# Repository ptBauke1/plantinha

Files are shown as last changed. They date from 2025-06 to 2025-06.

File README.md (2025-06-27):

# Monitor e Irrigador Automático de Vaso de Planta 🌱💧

## Descrição

Este projeto utiliza um sensor de umidade do solo resistivo para monitorar a umidade em um vaso de planta. Com base nas leituras do sensor, um sistema de controle aciona uma pequena bomba d'água para irrigar a planta automaticamente, garantindo que ela receba a quantidade ideal de água.

---

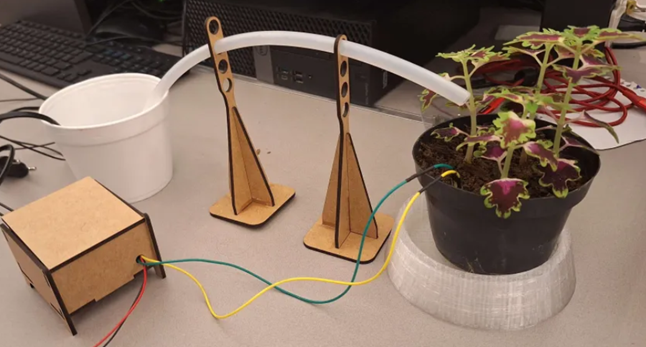
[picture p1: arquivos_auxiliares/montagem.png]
Texto Alternativo Montagem do projeto


## Estrutura do repositorio 📂
```
├─── main.cpp
├─── CmakeLists.txt
├─── pico_sdk_import.cmkae
├─── README.md
├─── Relatorio.pdf
├─── Apresentacao.pdf
├─── calibracao_sensor.xlsx
├───arquivos_auxiliares
├───include
│   └───ssd1306
├───projeto mecanico
│   ├───caixa
│   └───suporte
└───src
    └───ssd1306
```

## Funcionalidades ✨

* **Monitoramento em tempo real:** Acompanha a umidade do solo continuamente.
* **Irrigação automática:** Aciona a bomba d'água quando a umidade cai abaixo de um nível pré-definido.
---

## Hardware Necessário 🔩

* Raspberry Pi Pico
* Sensor de Umidade do Solo Resistivo
* Relé para controle da bomba d'Água
* Bomba d'Água Submersível AC
* Mangueira para a bomba
* Vaso de planta com terra e planta!

---

## Software e Bibliotecas 💻

* O software foi desenvolvido atraves do Visual Studio Code utilizando a SDK disponibilizada pela Raspberry Pi Foundation para o desenvolvimento de seus microcontroladores em C.
* Para o controle do display OLED, utilizou-se a biblioteca SSD1306_OLED, que pode ser conferida no link: https://github.com/gavinlyonsrepo/SSD1306_OLED_PICO
---

## Montagem e Conexões 🔌

Descreva aqui as conexões entre os componentes. Por exemplo:

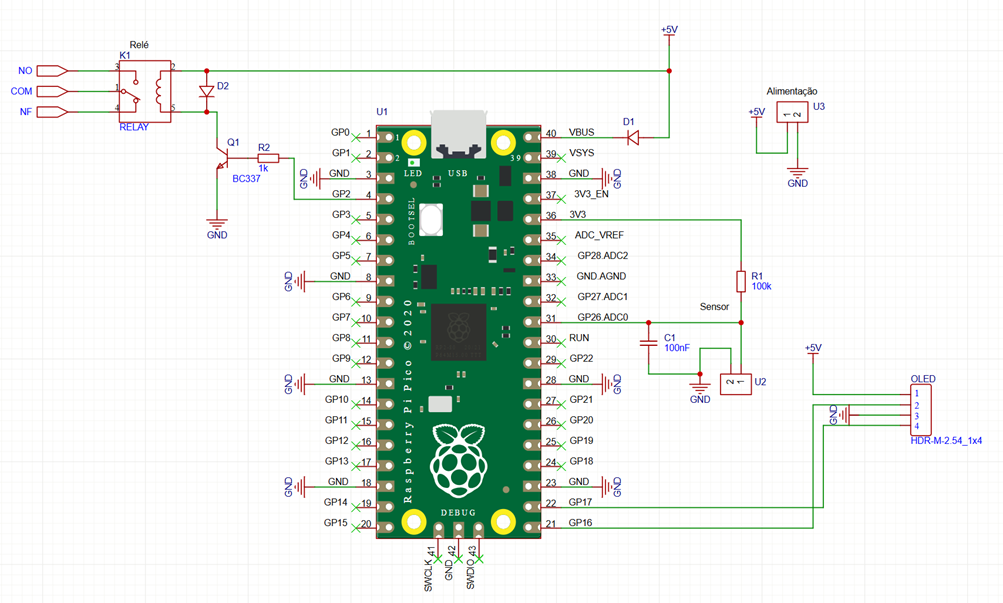
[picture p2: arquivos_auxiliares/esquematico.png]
Esquema eletrico

1.  **Sensor de Umidade:**
    * A variação da corrente do sensor é transformada em variação de tensão pelo divisor resistivo exitente entre o R1 e o proprio sensor 
    * A leitura do sensor é realizada pelo pino 31 da Raspberry Pi Pico, pino no qual o ADC0 do microcontrolador está conectado.
2.  **Módulo Relé e Bomba:**
    * **Módulo Relé:**
        * Base do transistor NPN conectado ao pino GPIO2 do microcontrolador
        * Coletor conectado a bobina do relé
        * Emissor conectado ao GND
        * Outra extremidade da bobina do relé conectada ao +5V.
    * **Bomba:**
        * Fase da bomba conectada ao NF do relé.
3.  **Display OLED**
    * Display conectado nos pinos GPIO16 e GPIO17, utilizando a comunição I2C.
4.  **Alimentação:**
    * Alimentação é fornecida por uma fonte de bancada configurada para +5V.

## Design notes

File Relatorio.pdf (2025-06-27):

Sistema Automatizado para Irrigação de Plantas

Eliana So 1

; Pedro Bauke 1

; Andressa Martins 2

; Rodrigo França 2

1 Aluno do Instituto Mauá de Tecnologia (IMT); 2 Professor do Instituto Mauá de Tecnologia (IMT).

Resumo. Este relatório técnico descreve o desenvolvimento de um sistema automatizado para irrigação de plantas, com foco em otimizar o manejo da umidade do solo em ambientes domésticos. O sistema emprega um sensor de umidade do solo resistivo, escolhido por sua simplicidade e baixo custo , que opera pela variação da resistência conforme a concentração de água e íons no solo. A estrutura mecânica foi construída com MDF e materiais reciclados, utilizando uma bomba d'água para o transporte do líquido. A eletrônica é controlada por um microcontrolador RP2040, que gerencia a leitura do sensor, o acionamento de um relé para a bomba e a exibição de dados em um display OLED. Para realizar a quantificação de umidade foi realizado uma calibração do sensor coletando-se dados do pino de ADC a partir de determinadas concentrações de água. O sistema funcionou devidamente, porém foram identificados problemas de alta sensibilidade do sensor e a necessidade de calibração para diferentes tipos de solo devido à variação na concentração de íons, o que exige ajustes para garantir medições precisas.

Introdução

A umidade é uma grandeza física fundamental em várias aplicações e a sua quantificação é essencial para otimizar desempenhos de sistemas, evitar perdas e gastos e garantir conforto à saúde humana. Para a sua medição são utilizados sensores de umidade que são amplamente utilizados em diversas áreas.
Em indústrias, por exemplo, monitora-se a umidade do ar para evitar problemas de ferrugem e danos às máquinas, além em indústrias alimentícias, controlam a qualidade do produto. No ambiente doméstico, os sensores são integrados em sistemas de aquecimento/refrigeração para otimizar a sua eficiência energética e melhorar a qualidade do ar reduzindo infecções respiratórias e alergias. Uso em agricultura, onde a concentração de água no solo é essencial para o rendimento das culturas, além disso, são ideais para prevenir o crescimento de mofo em plantas e solo.
É perceptível sua alta gama de aplicações em diversos setores, os quais alguns dos seus principais foram citados brevemente. Essa diversificação também se aplica à tecnologia empregada nos sensores, os principais e os mais populares tipos de sensores são os resistivos, capacitivos e de condutividade térmica.
Visando em uma aplicação para automação residencial e agricultura, optou-se a criação de um sistema de irrigação inteligente para vasos de planta domiciliar, visto que, de acordo com o Censo QuintoAndar de Moradia de 2021, 37% dos entrevistados relataram um aumento no hábito de cuidar de plantas ou de jardins durante a pandemia de COVID-19, além de 69% dos entrevistados gostam de cultivar plantas em seus lares.
Para a realização do sistema de irrigação para agradar os amantes de plantas, optou-se na confecção de um sensor de umidade resistivo pela sua simplicidade de design, baixo custo e capacidade de medir grandes variações de umidade.

Material e Métodos

Com o foco na automação residencial, optou-se por utilizar materiais de fácil acesso, como MDF e materiais reciclados, pois dessa forma se torna possível a reprodução do sistema em ambientes residenciais. Na Figura 1 está a montagem final do projeto.

Figura 1 – Montagem final

Mecânica

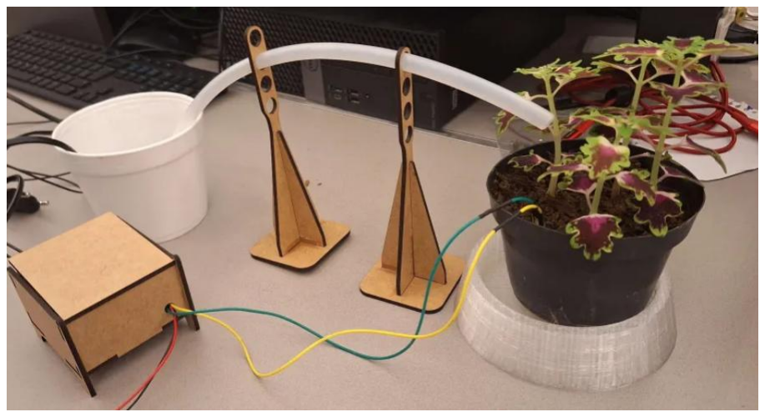
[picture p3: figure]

Para regar a planta é importante qualquer recipiente para armazenar água e um método de transportar o líquido para a planta. Optou-se no uso de um recipiente reciclável (vasilha de isopor) do tamanho ideal para caber uma bomba d’água, que no caso, utilizou-se de uma bomba para fonte de bebedouro para animais de estimação e um tubo de plástico de 10mm de diâmetro para o transportar a água para a planta.
O restante da parte estrutural, utilizou-se de chapas de MDF de 3mm, devido à versatilidade e rápida prototipação. A montagem é formada por um “corpo central”, definida por uma caixa com tampa basculante para comportar toda a eletrônica e um rasgo na parte frontal para o display, além disso, foram feitos “postes” reguláveis para arquear e suportar o tubo de plástico da bomba d’água, pois a fluidez da água depende da sua angulação.
Todos os componentes, para que sejam cortados no corte a laser, foram feitas no Solidworks como demonstra na Figura 2.

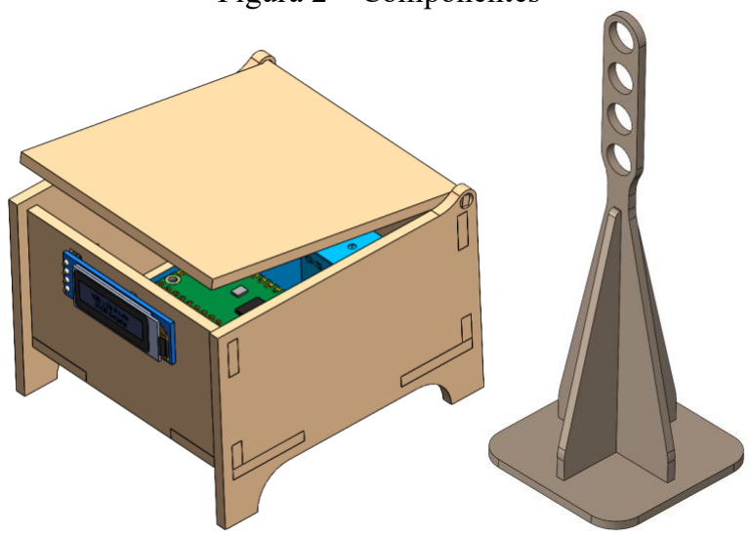
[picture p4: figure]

Figura 2 – Componentes

Sensor

O sensor desenvolvido é um sensor de umidade do solo resistivo, esse tipo de sensor consiste em basicamente dois eletrodos metálicos, ou seja, pode-se utilizar pregos, fios de cobre. A Figura 3 mostra a placa de circuito impresso com duas trilhas paralelas que servem como os eletrodos do sensor.

Figura 3 – Sensor de umidade do solo

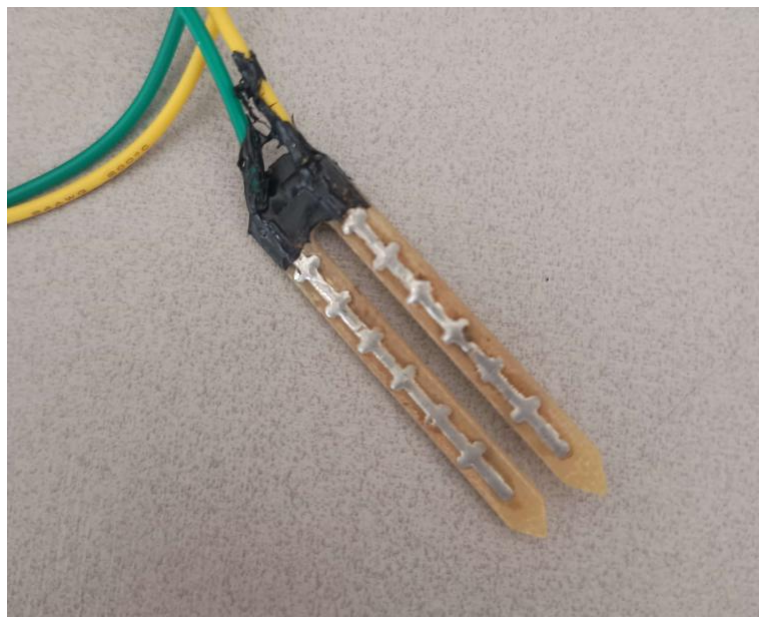
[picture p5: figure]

O sensor é composto por dois eletrodos que são inseridos no solo, e estabelecem uma conexão elétrica através dele. Por estar em constante contato com a umidade, o sensor é suscetível à oxidação e corrosão, um problema comum de se acontecer com eletrônicos, portanto, para aumentar a sua vida útil, as trilhas de cobres da placa foram estanhadas.
Seu funcionamento se dá pela variação da resistência do solo, ou seja, a capacidade do solo de resistir a passagem de corrente elétrica. Isso acontece devido a presença de íons dispersos no solo, e como a água também apresenta íons, quanto maior a concentração de água no solo, mais íons estarão presentes, dessa forma a resistividade diminui e mais elétrons conseguem atravessar entre os eletrodos do sensor.

Eletrônica

Para a criação e fabricação da placa de controle, foi montado o diagrama de blocos ilustrado pela Figura 4, que representa de maneira simples e clara como cada elemento do circuito se comunica, explicitando como os componentes trocam informações entre si.

Figura 4 – Diagrama de blocos do sistema

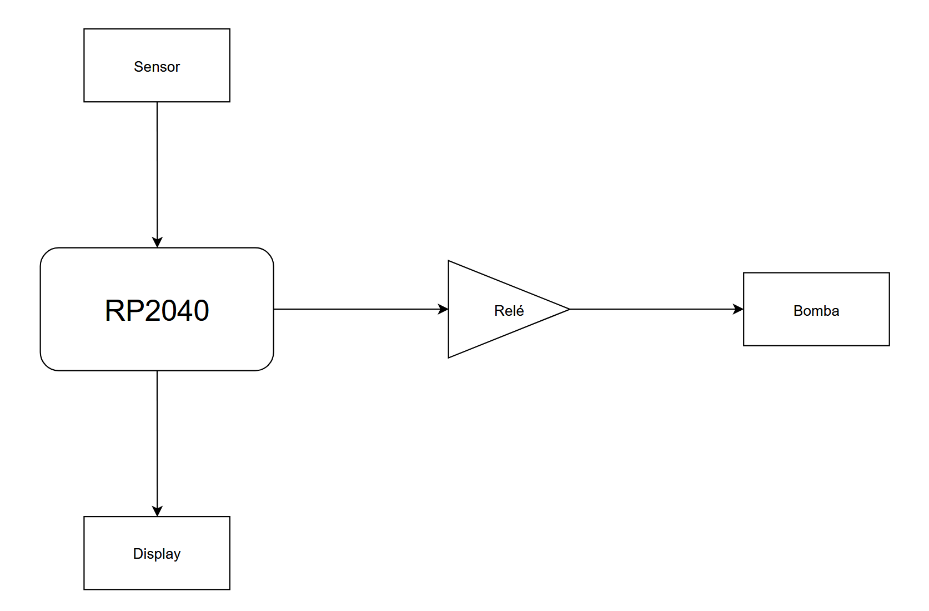
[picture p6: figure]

Com o diagrama de blocos montado, utilizou-se do software EasyEDA para a criação do esquema elétrico e da placa de circuito impresso. As Figura 5 e 6 apresentam o diagrame elétrico e a PCB, respectivamente.

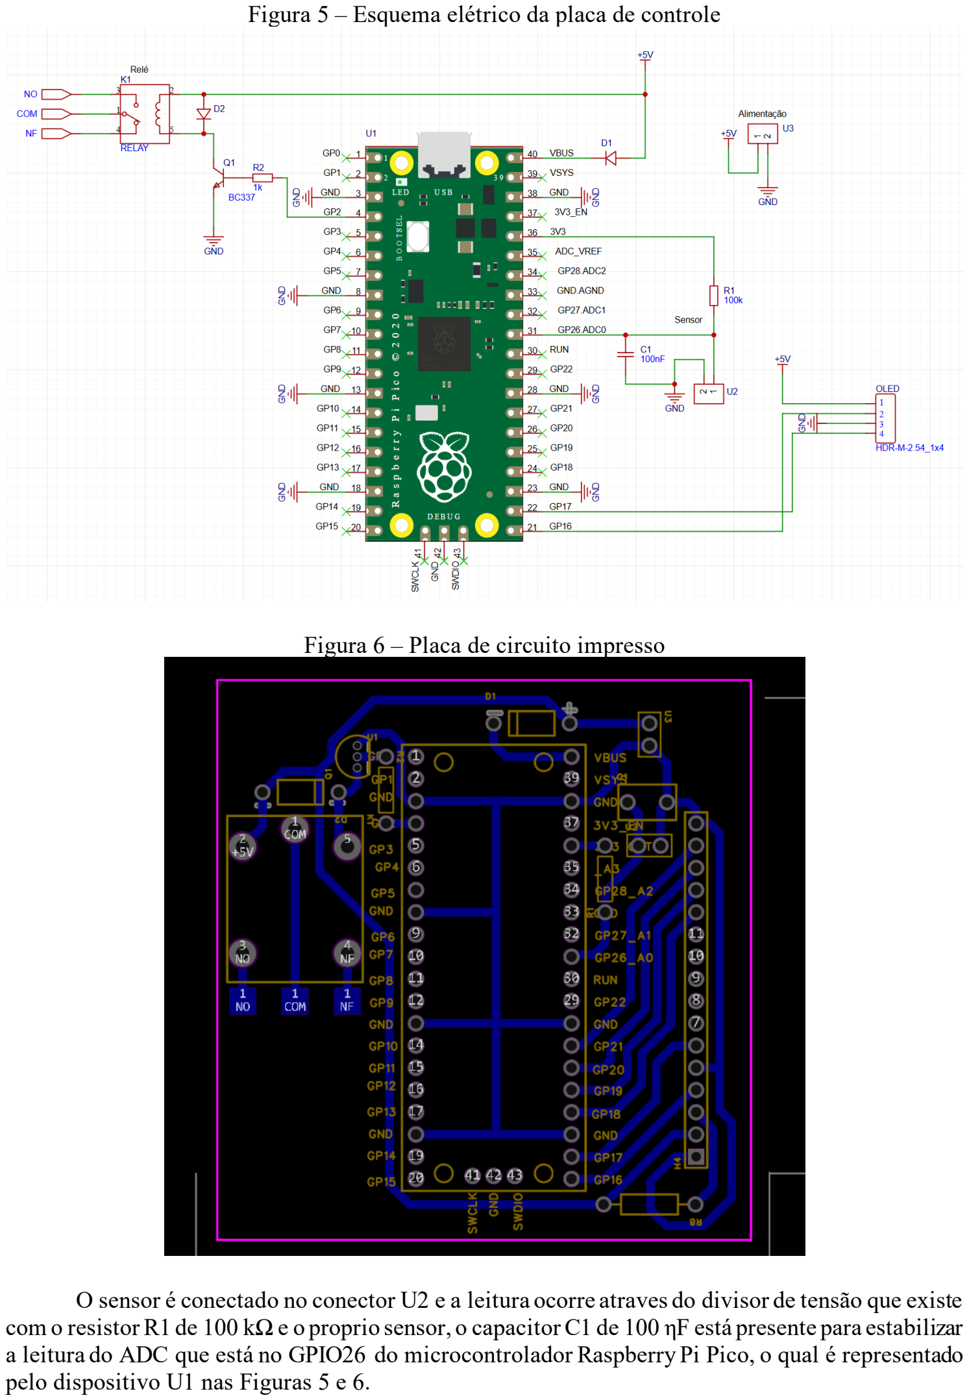
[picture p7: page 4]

Figura 5 – Esquema elétrico da placa de controle

Figura 6 – Placa de circuito impresso

O sensor é conectado no conector U2 e a leitura ocorre atraves do divisor de tensão que existe com o resistor R1 de 100 kΩ e o proprio sensor, o capacitor C1 de 100 ηF está presente para estabilizar a leitura do ADC que está no GPIO26 do microcontrolador Raspberry Pi Pico, o qual é representado pelo dispositivo U1 nas Figuras 5 e 6.

Para o acionamento da bomba, utiliza-se o relé 875B-1CC-F-S, uma vez que a bomba utilizada funciona em corrente alternada e o sistema de controle, em corrente continua. Como o relé necessita de um sinal de +5V para ser acionado e o microcontrolador tem como nível lógico alto +3,3V, um transistor foi adicionado no circuito, agindo como elemento que chaveia a parte que conecta a bobina do relé ao GND.
Além disso, o circuito apresenta um display OLED 128x32, que se comunica com o microcontrolador através do protocolo I2C, para exibir informações como a umidade relativa do solo e o valor lido pelo conversor analógico-digital do RP2040, ilustrado na Figura 7. A PCB apresenta uma barra de 16 vias pois em seua versão inicial, um display LCD era considerado como forma de apresentar as informações.

Figura 7 – Visor OLED para apresentação dos dados

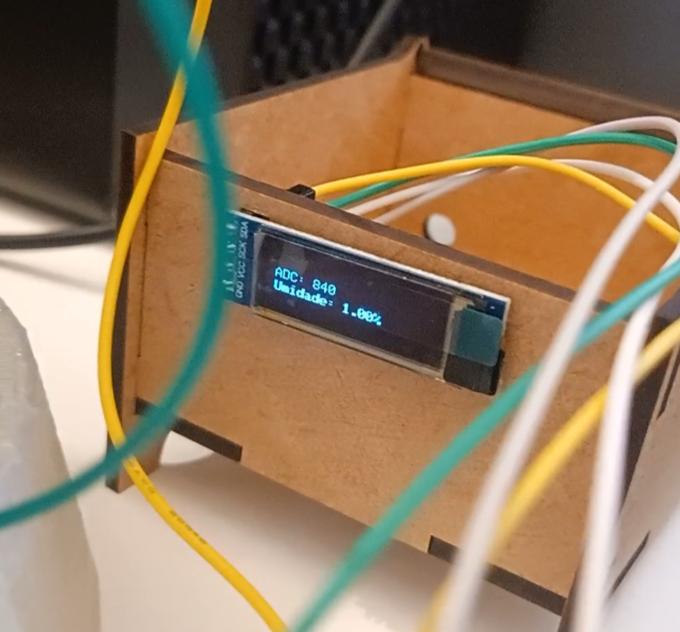
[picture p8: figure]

A alimentação da placa de controle é realizada através dos conectores U3, nos quais fios são soldados e na outra ponta desses fios conectam em cabos banana-jacaré conectados a uma fonte de bancada que fornece +5V ao sistema.

Calibração

Para conseguir mensurar o que o sensor está lendo, é imprescindível fazer sua calibração. O processo foi realizado utilizando uma amostra de 78,22g de terra seca e para cada 5 minutos, 6,37ml de água (equivalente ao volume de uma tampinha de garrafa) foram adicionados na amostra. Os valores de ADC, quando estabilizados, foram coletados em cada iteração e anotados na Tabela 1.

Tabela 1 – Dados coletados
Valor ADC | Água (ml) | Concentração de água (%)
3600 | 0,00 | 0,000
2270 | 6,37 | 8,145
1440 | 12,74 | 16,290
1210 | 19,11 | 24,435
1140
1135
1125
1113
1109
1110

25,48
31,86
38,23
44,60
50,97
57,34
63,71
70,08

32,580
40,725
48,870
57,016
65,161
73,306
81,451
89,596

A coluna de concentração de água foi determinada utilizando a quantidade de água acumulada dividida pela massa da amostra do solo, o qual denota um valor importante para a quantização de água no solo, e consecutivamente, o valor ideal para a planta.
É importante notar empiricamente que a partir de 31,86ml de água (equivalente a 1135 em ADC), o solo atinge a saturação, tornando-o extremamente úmido. Ressalta-se também, através da tabela, a baixa variação nos valores de ADC para esse estado, portanto, é desprezável os valores a partir do 6º ponto.
Com os dados entre 8,145% a 40,725%, o Gráfico 1 esboça a curva comportamental do sensor permitindo que sua tendência seja utilizada para estimar a concentração de água no vaso de plantas.

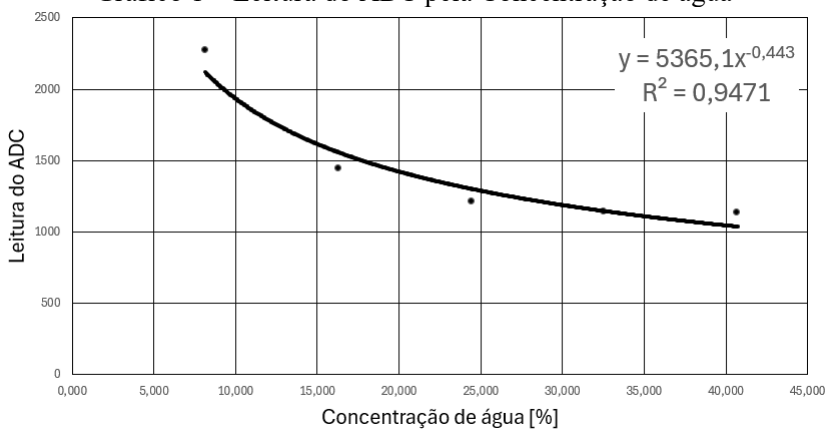
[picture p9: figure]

Gráfico 1 – Leitura do ADC pela Concentração de água

Código

Na parte do software, para a constante observação do estado do solo e verificar a necessidade de rega, a leitura do sensor é realizada via interrupção de timer, em um intervalo de 500ms. No loop principal, ocorre a conversão do valor lido pelo ADC em um valor de umidade relativa do solo, utilizando-se da Equação I, obtida através da calibração do sensor.

%umidade = (

adcraw
5365,1

)

−2,257
(I)

Além dessa conversão, realiza-se uma transformação na escala da umidade, uma vez que o sensor construído consegue medir apenas no intervalo de 10,00% a 40,00% de umidade relativa do solo. Ou seja, o intervalo de leitura do sensor é transformado em uma escala de 0% a 100,00%. Com o valor convertido, uma comparação ocorre para verificar se o relé deve ser acionado, caso o valor lido represente uma umidade abaixo de um determinado patamar, o relé é ligado, e a partir do momento em que o sensor ler acima desse patamar novamente, inicia-se um timer que desliga a bomba 1,0 segundo após seu início. Após o desacionamento do relé, um segundo timer, que tem 120 segundos de duração é iniciado, de forma a garantir que o sensor possa estabilizar sua leitura antes de que o fluxo de água seja religado.
Por fim, ainda no loop principal temos a atualização do display OLED com as informações mais recentes de umidade e valor lido pelo ADC da Raspberry Pi Pico representado na Figura 7. O código pode ser verificado em sua integridade no repositório do GitHub do projeto. (https://github.com/ptBauke1/plantinha)

Resultados e Discussão

Em um contexto geral, todo o sistema funcionou devidamente, foi possível observar uma variação da resistência entre os eletrodos do sensor na faixa dos 80kΩ, sendo que em solo seco o sensor apresentava uma elevada resistência, mais especificamente um valor de 100kΩ, e no solo úmido, 20kΩ, ou seja, uma resistência baixa quando comparada ao valor medido no solo seco. Foi possível de visualizar essa mudança de resistência por meio da entrada analógica (GPIO26 de ADC) do Raspberry Pi Pico, que estava conectada ao divisor de tensão resistivo. A escolha do microcontrolador foi essencial para o funcionamento de automatização da bomba d’agua com customização de valor delimitante para a irrigação em momentos exatos.
Observou-se dois principais problemas que impactaram levemente o funcionamento do sistema. O primeiro foi a elevada sensibilidade do sensor, uma vez que o sinal apresentava rápidas variações quando o sistema se encontrava em estabilidade, isso poderia ser amenizado com a implementação de um filtro passa baixas entre o sensor e o microcontrolador.Esse problema também acarretou um elevado tempo de resposta do sensor.
O segundo problema é referente à composição do solo no qual o sensor é inserido, percebeu-se que os valores limites de terra seca e terra molhada variam dependendo do tipo do solo. Segundo Thiago Rogério, diversos fatores influenciam a condutividade elétrica do solo, incluindo a textura do solo, a umidade, a temperatura e a composição química, ou seja, em solos mais ricos em nutrientes e matéria orgânica possuem uma concentração maior de íons quando comparados em terras pobres. Isso acarreta a necessidade de realizar a calibração do sensor em cada tipo de solo para garantir medições precisas.

Conclusões

O sistema automatizado para irrigação de plantas demonstrou funcionalidade e eficácia geral, cumprindo o objetivo de monitorar a umidade do solo e realizar a rega de forma autônoma. A escolha do sensor resistivo se mostrou adequada pela simplicidade e custo-benefício, e o microcontrolador Raspberry Pi Pico foi essencial para a automatização e customização do processo de irrigação.
No entanto, foram identificados os desafios significativos de filtragem do sinal e considerações de qualidade dos solos que merecem consideração em futuros aprimoramentos. Apesar desses pontos, o projeto valida a viabilidade de um sistema de irrigação inteligente e acessível para uso doméstico, alinhado ao crescente interesse em cultivo de plantas em ambientes residenciais. Melhorias futuras devem focar na estabilização da leitura do sensor e no desenvolvimento de métodos de calibração mais versáteis para diferentes composições de solo.

Referências Bibliográficas

### 7 em cada 10 brasileiros gostam de ter e cuidar de plantas. 2022. Disponível em:

https://alnb.com.br/brasil/7-em-cada-10-brasileiros-gostam-de-ter-e-cuidar-de-plantas/. Acesso em: 25 jun. 2025.
BRUNO DRUMOND. Resistividade do solo: o que é e como fazer sua medição. 2023. Disponível em: https://adequada.eng.br/resistividade-solo/#elementor-toc__heading-anchor-0. Acesso em: 25 jun. 2025.
SENSOR ONE STOP. How to Choose Humidity Sensors: A Comprehensive Guide. 2024. Disponível em: https://sensor1stop.com/knowledge/how-to-choose-humidity-sensors/. Acesso em: 25 jun. 2025.
THIAGO ROGÉRIO. O que é condutividade elétrica do solo: fatores que afetam a condutividade elétrica do solo. Fatores que afetam a condutividade elétrica do solo. 2024. Disponível em: https://www.bienaldaagricultura.com.br/glossario/o-que-e-condutividade-eletrica-do-solo/. Acesso em: 26 jun. 2025.

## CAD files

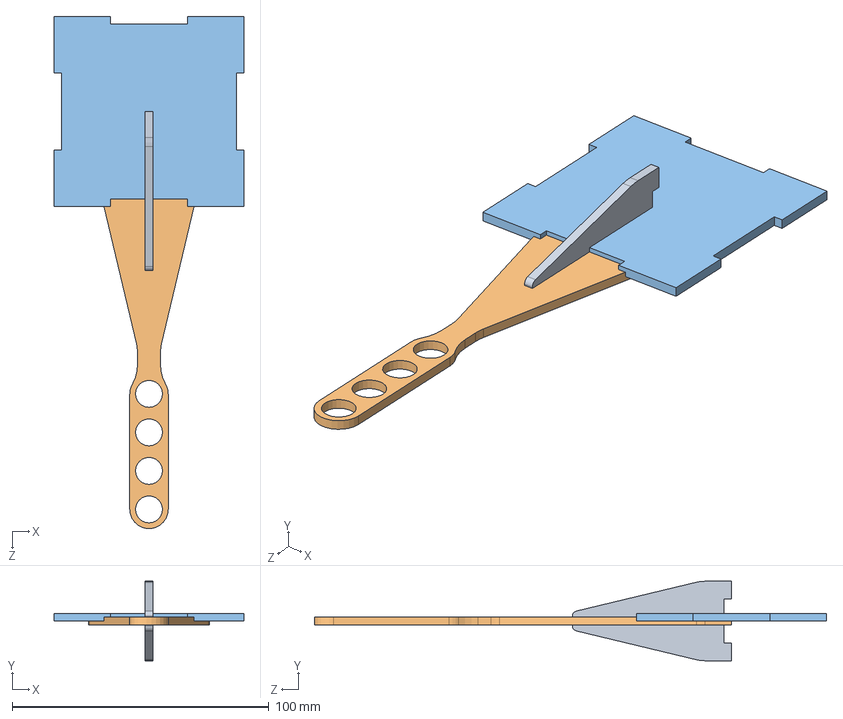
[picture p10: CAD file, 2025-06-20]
projeto mecanico/suporte/montagem.SLDASM
74.0 x 31.0 x 199.4 mm
base
haste1
haste2

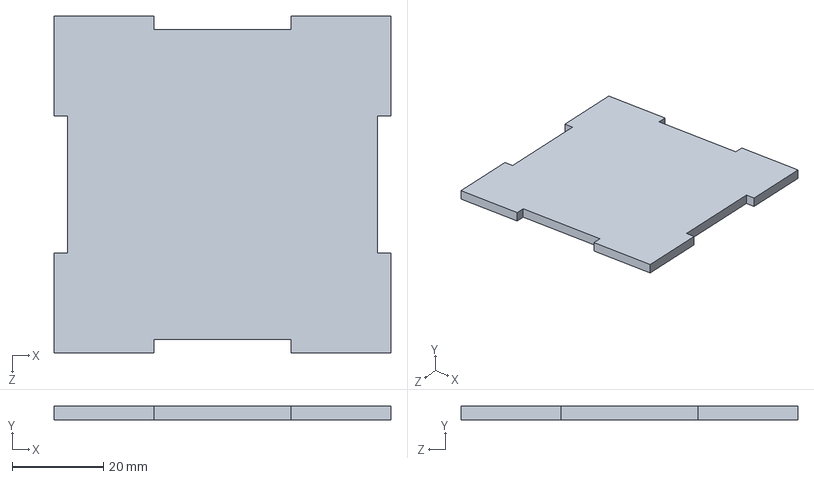
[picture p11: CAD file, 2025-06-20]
projeto mecanico/caixa/base.SLDPRT
74.0 x 3.00 x 74.0 mm

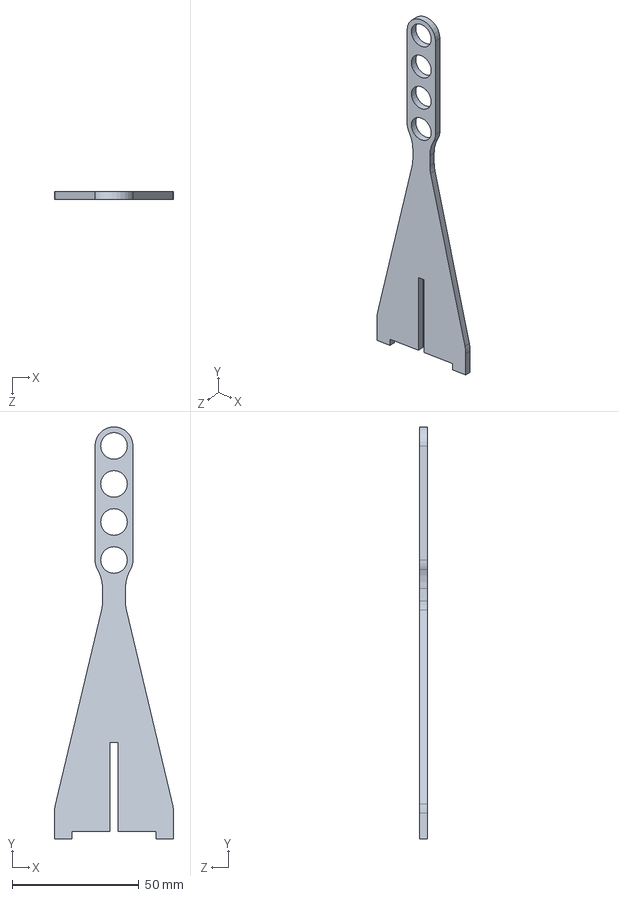
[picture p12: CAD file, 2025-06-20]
projeto mecanico/suporte/haste1.SLDPRT
47.0 x 162.4 x 3.00 mm

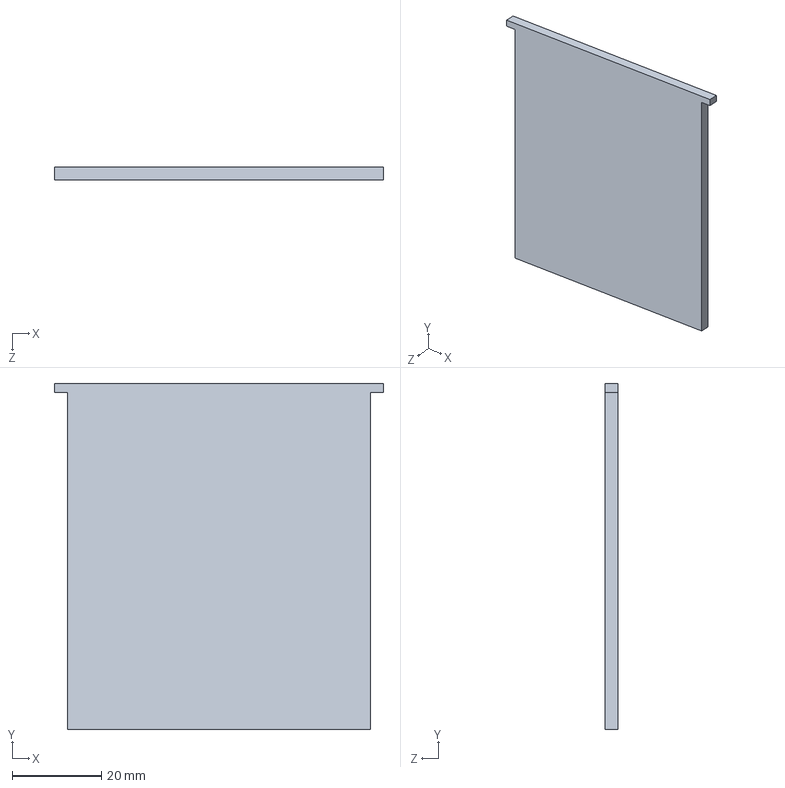
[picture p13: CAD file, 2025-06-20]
projeto mecanico/caixa/tampa.SLDPRT
73.8 x 77.5 x 3.00 mm

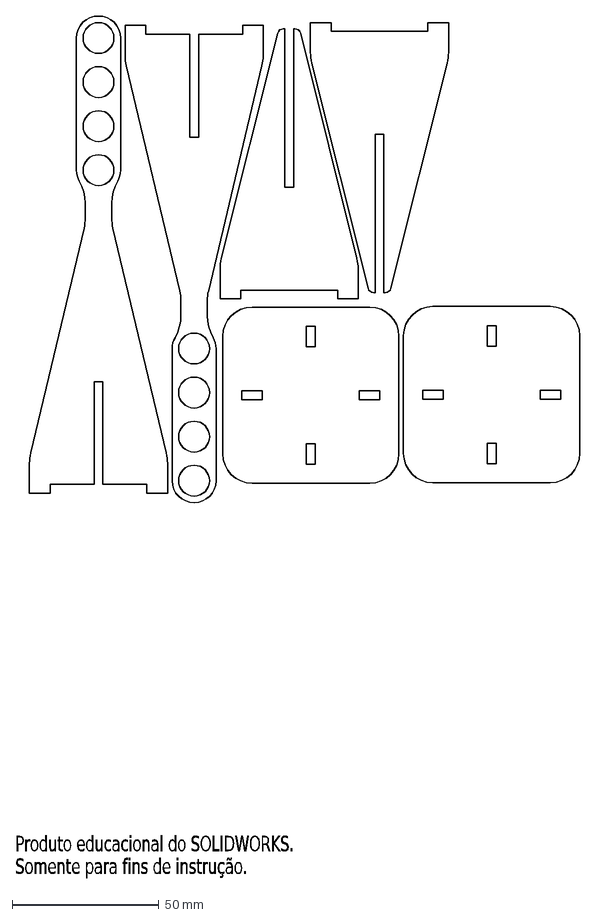
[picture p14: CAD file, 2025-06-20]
projeto mecanico/suporte/base_laser.DXF
Produto educacional do SOLIDWORKS.
Somente para fins de instrução.

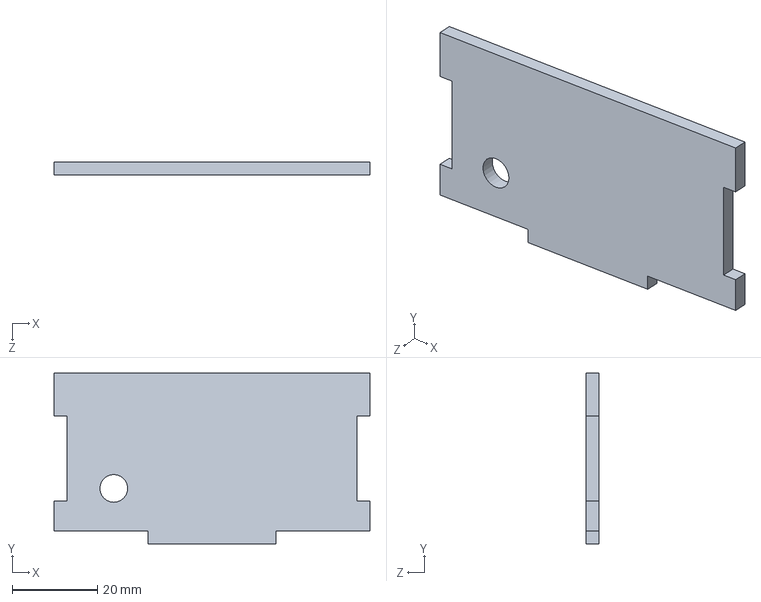
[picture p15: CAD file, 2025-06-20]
projeto mecanico/caixa/lateral 1.SLDPRT
74.0 x 40.0 x 3.00 mm

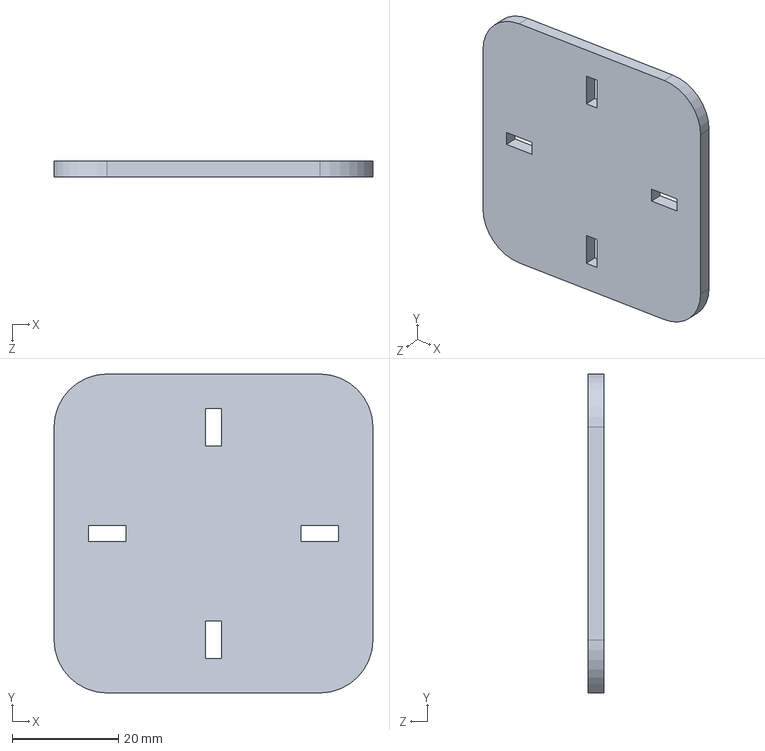
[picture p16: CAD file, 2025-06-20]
projeto mecanico/suporte/base.SLDPRT
60.0 x 60.0 x 3.00 mm

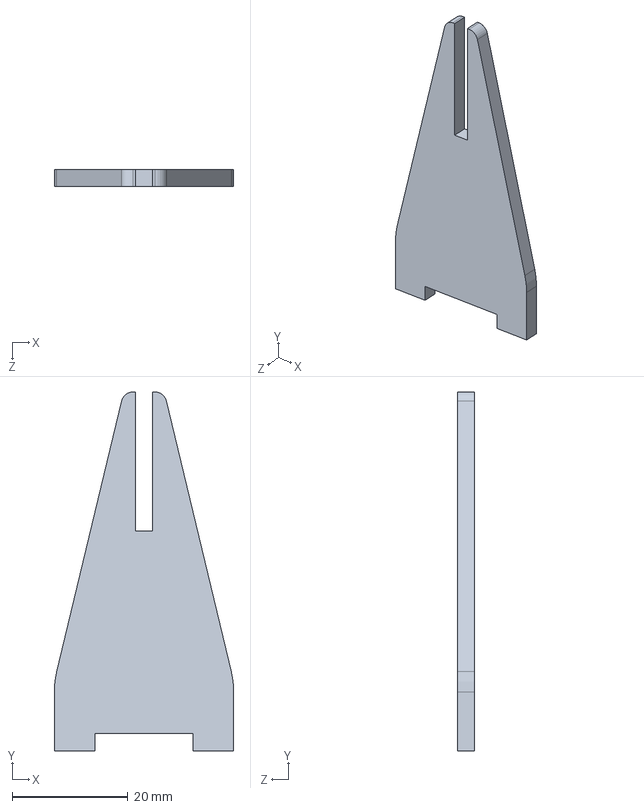
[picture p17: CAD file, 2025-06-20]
projeto mecanico/suporte/haste2.SLDPRT
31.0 x 62.0 x 3.00 mm

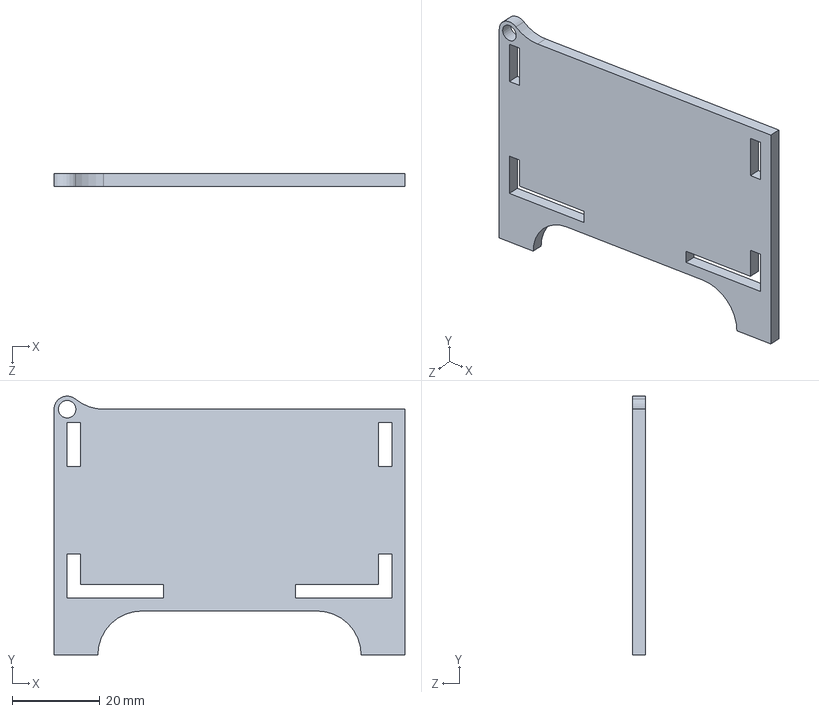
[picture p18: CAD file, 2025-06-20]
projeto mecanico/caixa/lateral 2.SLDPRT
80.0 x 59.0 x 3.00 mm

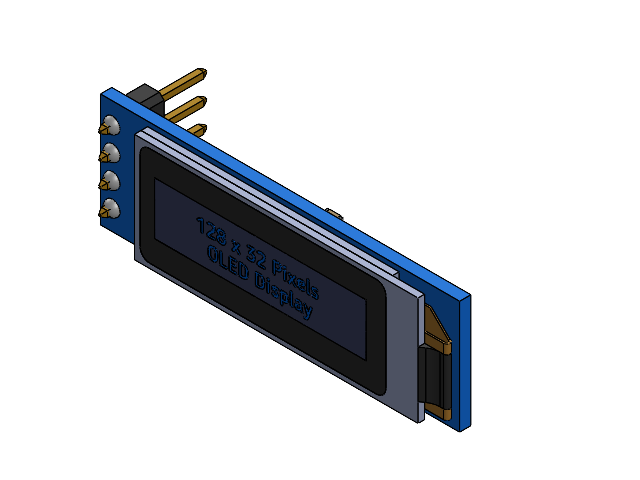
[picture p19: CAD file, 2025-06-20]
projeto mecanico/caixa/OLED 128 x 32 Display Assembly.SLDASM
Board_001.step
1x4 Male Header_001.step
0603 Capacitor_001.step
0603 Capacitor_002.step
0603 Capacitor_003.step
0603 Capacitor_004.step
0603 Capacitor_005.step
0603 Capacitor_006.step
0603 Capacitor_007.step
0603 Capacitor_008.step
0603 Resistor_001.step
0603 Resistor_002.step
0603 Resistor_003.step
0603 Resistor_004.step
0603 Resistor_005.step
Surface Mount Transistor_001.step

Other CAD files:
projeto mecanico/caixa/frontal.SLDPRT
projeto mecanico/suporte/base_laser.SLDDRW

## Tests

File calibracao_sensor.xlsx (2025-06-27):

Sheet: Planilha1
adc | % agua
700 | 1
850 | 0.9
2900 | 0

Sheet: Planilha2
ADC | ml | % de água
3700 | 0 | 0 | massa= | 107.45 | g
1350 | 6.371 | 5.929269428 | tampinha= | 6.371 | ml
1180 | 12.742 | 11.85853886
1180 | 19.113 | 17.78780828
1140 | 25.484 | 23.71707771
1130 | 31.855 | 29.64634714
1120 | 38.226 | 35.57561657
 | 44.597 | 41.50488599
 | 50.968 | 47.43415542
700 | 57.339 | 53.36342485
 | 63.71 | 59.29269428
 | 70.081 | 65.2219637
 | 76.452 | 71.15123313
 | 82.823 | 77.08050256
 | 89.194 | 83.00977199
 | 95.565 | 88.93904141
 | 101.936 | 94.86831084

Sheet: Planilha3
ADC | água (ml) | % água | Obs.:
3600 | 0.00 | 0.000 | Solo Seco | Massa da amostra de solo | 78.219 | g
2270 | 6.37 | 8.145
1440 | 12.74 | 16.290
1210 | 19.11 | 24.435
1140 | 25.48 | 32.580
1135 | 31.86 | 40.725 | Saturação (Solo extremamente úmido)
1125 | 38.23 | 48.870
1113 | 44.60 | 57.016
1109 | 50.97 | 65.161
1110 | 57.34 | 73.306
- | 63.71 | 81.451
- | 70.08 | 89.596
Massa da amostra de solo |  | 78.219 | g

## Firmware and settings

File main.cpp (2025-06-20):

#include "pico/stdlib.h"
#include "hardware/gpio.h"
#include "hardware/adc.h"

#include "hardware/i2c.h"

// Inclua o header principal da sua biblioteca OLED
#include "include/ssd1306/SSD1306_OLED.hpp" // Ajuste o caminho conforme sua estrutura

#include <stdio.h>
#include <math.h>

#define PIN_RELE 2
#define PIN_SENSOR 26

#define ADC_MAXREADING 3500 // -> Solo seco (valor máximo do ADC)
#define ADC_MINREADING 600 // -> sensor imerso em água (valor mínimo do ADC)

#define MAX_CONCENTRATION 40.0f // Concentração máxima de umidade (100%)
#define MIN_CONCENTRATION 8.0f // Concentração mínima de umidade (0%)

#define HUMIDITY_THRESHOLD 40.0f // Limite de umidade para ativar o relé (40%)
#define PUMP_INTERVAL_US 1000000 // Intervalo de tempo para o relé (1,0 segundo)
#define RELE_INTERVAL_US 120000000 // Intervalo de tempo para o relé 
// 1,0 segundos em us = 1.0 * 1000000 = 1000000 us
// 2 minutos em us = 2 * 60 * 1000000 = 120000000 us

struct repeating_timer timer;

uint16_t adc_raw_value = 0; // Variável para armazenar o valor lido do ADC
float humidity_percentage = 0.0f; // Variável para armazenar a umidade em porcentagem
uint32_t pump_timer = 0; // Timer para controlar o relé
uint32_t rele_time = 0; // Tempo do último acionamento do relé
bool flag_rele = true; // Flag para controlar o estado do relé
// --- Configurações Globais para o OLED e Wrappers ---
const int16_t OLED_WIDTH = 128;
const int16_t OLED_HEIGHT = 32; // Mude para 32 se for um display 128x32

// Buffer para o display
uint8_t oled_main_buffer[OLED_WIDTH * (OLED_HEIGHT / 8)];

// Objeto OLED Global (usado pelas funções wrapper)
SSD1306 oled(OLED_WIDTH, OLED_HEIGHT);
bool oled_is_initialized = false;

// Configurações I2C Padrão (podem ser sobrescritas na função oled_init)
#define I2C_INSTANCE i2c0
#define I2C_SDA_PIN 16
#define I2C_SCL_PIN 17
#define DEFAULT_I2C_CLOCK_SPEED 100 // kHz
#define DEFAULT_OLED_I2C_ADDRESS SSD1306_ADDR // 0x3C


bool repeating_timer_callback(struct repeating_timer *t) {
    adc_raw_value = adc_read(); // Lê o valor do ADC
    return true;
}

void convert_adc(){
    // Converte o valor lido do ADC para porcentagem de umidade (0 a 100%)
    // if (adc_raw_value >= ADC_MAXREADING) {
        // humidity_percentage = 0.0f; // Garante que o valor não seja maior que o máximo
    // } else if (adc_raw_value <= ADC_MINREADING) {
        // humidity_percentage = 100.0f; // Garante que o valor não seja menor que o mínimo
    // } else {
        //Converte o valor do ADC para porcentagem de umidade
        // humidity_percentage = ((float)(ADC_MAXREADING - adc_raw_value) / (ADC_MAXREADING - ADC_MINREADING)) * 100.0f;
    // }
    // humidity_percentage  = (5365.1f/ adc_raw_value) ^ 2.2573f
    if (adc_raw_value <= 700) {
        humidity_percentage = 100.0f; // Evita divisão por zero
    } else if (adc_raw_value >= 2500) {
        humidity_percentage = 0.0f; // Evita valores negativos
    } else {
        humidity_percentage = pow((5365.1f / adc_raw_value), 2.2573f);
    }
    humidity_percentage = (humidity_percentage - MIN_CONCENTRATION) / (MAX_CONCENTRATION - MIN_CONCENTRATION) * 100.0f;
    if (humidity_percentage < 0.0f) {
        humidity_percentage = 0.0f; // Garante que o valor não seja negativo
    } else if (humidity_percentage > 100.0f) {
        humidity_percentage = 100.0f; // Garante que o valor não ultrapasse 100%
    }
}

void control_relay() {
    // Controla o relé com base na umidade, ligando o relé por um tempo, mas sem travar o programa
    // depois que o relé desativar, trava o relé por um tempo definido, para o sensor conseguir estabilizar
    if (!flag_rele) { 
        if (time_us_32() - rele_time >= RELE_INTERVAL_US) {
            flag_rele = true; // Destrava a possibilidade de ativar o relé
            gpio_put(PIN_RELE, false); // Garante que o relé esteja desligado
        }
        else {
            return;
        }
    }
    if (humidity_percentage < HUMIDITY_THRESHOLD) {
        // Se a umidade estiver abaixo do limite, ativa o relé
        gpio_put(PIN_RELE, true);
        pump_timer = time_us_32();
    }
    if (time_us_32() - pump_timer >= PUMP_INTERVAL_US) {
        gpio_put(PIN_RELE, false);
        flag_rele = false; // Desativa o relé
        rele_time = time_us_32(); // Atualiza o tempo do relé
        }
}

// --- Funções Wrapper para Simplificar o Uso do OLED ---

/**
 * @brief Inicializa o display OLED.
 * Configura o buffer e inicializa a comunicação I2C com o display.
 * Deve ser chamada uma vez antes de usar as outras funções oled_*.
 */
bool oled_init(i2c_inst_t* i2c_instance = I2C_INSTANCE,
               uint8_t sda_pin = I2C_SDA_PIN,
               uint8_t scl_pin = I2C_SCL_PIN,
               uint16_t clk_speed_khz = DEFAULT_I2C_CLOCK_SPEED,
               uint8_t i2c_address = DEFAULT_OLED_I2C_ADDRESS) {
    if (oled_is_initialized) {
        printf("OLED ja inicializado.\n");
        return true;
    }

    uint8_t buffer_status = oled.OLEDSetBufferPtr(OLED_WIDTH, OLED_HEIGHT, oled_main_buffer, sizeof(oled_main_buffer));
    if (buffer_status != 0) {
        printf("oled_init: Erro ao configurar o buffer: %d\n", buffer_status);
        return false;
    }

    if (!oled.OLEDbegin(i2c_address, i2c_instance, clk_speed_khz, sda_pin, scl_pin)) {
        printf("oled_init: Falha ao iniciar o OLED via OLEDbegin.\n");
        return false;
    }

    oled_is_initialized = true;
    printf("OLED inicializado com sucesso.\n");
    return true;
}

/**
 * @brief Limpa o buffer do display.
 * Por padrão, atualiza o display (envia o buffer limpo).
 */
void oled_clear(bool update_now = true) {
    if (!oled_is_initialized) {
        printf("oled_clear: OLED nao inicializado.\n");
        return;
    }
    oled.OLEDclearBuffer();
    if (update_now) {
        oled.OLEDupdate();
    }
}

/**
 * @brief Envia o conteúdo do buffer para o display OLED.
 */
void oled_display() {
    if (!oled_is_initialized) {
        printf("oled_display: OLED nao inicializado.\n");
        return;
    }
    oled.OLEDupdate();
}

/**
 * @brief Escreve uma string de texto (pré-formatada) no display.
 *
 * @param x Posição X inicial do texto.
 * @param y Posição Y inicial do texto.
 * @param formatted_text A string de texto já formatada a ser escrita.
 * @param font Ponteiro para a fonte a ser usada (default: pFontDefault).
 * Use nullptr para manter a fonte atualmente selecionada pela biblioteca.
 * @param update_now Se true, atualiza o display imediatamente.
 */
void oled_write_text(int16_t x, int16_t y, const char* formatted_text, const uint8_t* font = pFontDefault, bool update_now = true) {
    if (!oled_is_initialized) {
        printf("oled_write_text: OLED nao inicializado.\n");
        return;
    }
    if (font != nullptr) {
        oled.setFont(font);
    }
    oled.setCursor(x, y);
    oled.print(formatted_text); // oled.print() da classe Print herdada.
    if (update_now) {
        oled_display();
    }
}

/**
 * @brief Desenha um pixel no buffer do display.
 */
void oled_draw_pixel(int16_t x, int16_t y, uint8_t color, bool update_now = true) {
    if (!oled_is_initialized) {
        printf("oled_draw_pixel: OLED nao inicializado.\n");
        return;
    }
    oled.drawPixel(x, y, color);
    if (update_now) {
        oled_display();
    }
}

char adc_text_buffer[32];
char humidity_text_buffer[32];

// --- Função Principal ---
int main() {
    stdio_init_all(); // Inicializa stdio para debug (opcional)
    gpio_init(PIN_RELE); // Inicializa o pino do relé
    gpio_set_dir(PIN_RELE, GPIO_OUT); // Define o pino do relé como saída
    
    adc_init(); // Inicializa o ADC
    adc_gpio_init(PIN_SENSOR); // Inicializa o pino do sensor como ADC
    adc_select_input(0); // Seleciona o canal ADC 0 (pino 26)

    if (!add_repeating_timer_us(-500000, repeating_timer_callback, NULL, &timer)) {
        printf("Falha ao adicionar o timer!\n");
        return 1;
    }

    // Inicializa o OLED
    if (!oled_init(I2C_INSTANCE, I2C_SDA_PIN, I2C_SCL_PIN, DEFAULT_I2C_CLOCK_SPEED, DEFAULT_OLED_I2C_ADDRESS)) {
        printf("Erro ao inicializar o OLED.\n");
        return 1;
    }

    oled_clear(); // Limpa o buffer do OLED

    while (true) {
        convert_adc(); // Converte o valor do ADC para porcentagem de umidade
        control_relay(); // Controla o relé com base na umidade
        snprintf(adc_text_buffer, sizeof(adc_text_buffer), "ADC: %d", adc_raw_value);
        snprintf(humidity_text_buffer, sizeof(humidity_text_buffer), "Umidade: %.2f%%", humidity_percentage);
        // Atualiza o OLED com os valores lidos
        oled_clear(false); // Limpa o buffer do OLED
        oled_write_text(5, 12, adc_text_buffer, pFontDefault, false);      // Escreve valor do ADC, não atualiza
        oled_write_text(5, 22, humidity_text_buffer, pFontDefault, false); // Escreve valor do contador, não atualiza
        oled_display(); // Atualiza o OLED com os dados do buffer
        sleep_ms(250);
    }   

    return 0;
}

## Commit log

2025-06-20 add proj mecanico
    [OLED 128 x 32 Display Assembly.SLDASM, base.SLDPRT, base_laser.DXF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]
2025-06-27 add relatorio, apresentacao e excel
    [calibracao_sensor.xlsx]
